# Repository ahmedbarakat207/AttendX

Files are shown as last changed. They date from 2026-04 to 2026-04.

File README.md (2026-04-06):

<div align="center">

# AttendX

**RFID-based Attendance Management System**

*ESP32 · MFRC522 · SSD1306 OLED · DS1302 RTC · Built-in Web Dashboard*





</div>

---

# Gallary

WhatsApp Image 2026-04-06 at 20 09 28

WhatsApp Image 2026-04-06 at 12 34 46

---

## What is AttendX?

AttendX is a self-contained, battery-powered attendance system. Students tap an RFID card — the device logs the scan with a timestamp and makes the record instantly available on a built-in web dashboard accessible from any phone or laptop. No internet connection, no external server, no apps to install.

The ESP32 acts as its own Wi-Fi access point. Everything runs on the device.

---

## Features

- **RFID scanning** — ISO 14443-A cards via MFRC522
- **OLED display** — 9 display modes, yellow/blue SSD1306
- **Built-in web dashboard** — admin panel served directly from ESP32
- **Battery powered** — 3.7 V Li-ion + TP4056 USB-C charger
- **DS1302 RTC** — keeps time through power cuts (CR2032 backup)
- **Dual Wi-Fi** — standalone AP mode or connect to existing network
- **SPIFFS storage** — student roster and attendance records survive reboots
- **CSV export** — download attendance sheet from the dashboard
- **Real-time updates** — SSE push to admin panel on every scan
- **One-button navigation** — cycle OLED modes without touching a phone

---

## Hardware

### Bill of Materials

| Component | Qty | Notes |
|---|-----|---|
| ESP32 Dev Board | 1 | Dual-core 240 MHz, 4 MB flash |
| MFRC522 RFID Module | 1 | 13.56 MHz, ISO 14443-A |
| SSD1306 OLED 0.96" | 1 | 128×64 px, I2C |
| DS1302 RTC Module | 1 | With CR2032 coin cell |
| CR2032 Coin Cell | 1 | RTC backup battery |
| TP4056 Charger Board | 1 | USB Type-C |
| Li-ion Battery 3.7 V | 1 | 18650 or flat LiPo |
| Tactile Button | 1 | OLED mode cycling |
| Power Switch | 1 | SPDT |
| 3D Printed Housing | 1 | 120 × 90 × 35 mm, 1.2 mm walls |

### Wiring

#### MFRC522 RFID → ESP32

| RFID Pin | ESP32 Pin |
|---|---|
| 3.3 V | 3.3 V rail |
| GND | GND |
| RST | GPIO 4 |
| SDA (SS) | GPIO 5 |
| MOSI | GPIO 23 |
| MISO | GPIO 19 |
| SCK | GPIO 18 |
| IRQ | — (not connected) |

#### SSD1306 OLED → ESP32

| OLED Pin | ESP32 Pin |
|---|---|
| VCC | 3.3 V rail |
| GND | GND |
| SCL | GPIO 22 |
| SDA | GPIO 21 |

#### DS1302 RTC → ESP32

| RTC Pin | ESP32 Pin | Notes |
|---|---|---|
| VCC | 3.3 V rail | |
| GND | GND | |
| CLK | GPIO 17 (TX2) | Repurposed UART2 TX |
| DAT | GPIO 16 (RX2) | Repurposed UART2 RX |
| RST | GPIO 1 (TX0) | Repurposed UART0 TX — USB Serial disabled |

#### Other

| Signal | ESP32 Pin |
|---|---|
| Button | GPIO 15 (INPUT_PULLUP) |
| Speaker | GPIO 2 |

> ⚠️ **All peripherals run on the 3.3 V rail. Do not connect anything to VIN/5 V.**  
> ⚠️ USB Serial (`Serial.print`) is **disabled** — GPIO1 (TX0) is used by the DS1302 RST line.

---

## Software

### Required Libraries

Install all of these from the Arduino Library Manager:

| Library | Purpose |
|---|---|
| `Adafruit GFX` | Graphics primitives |
| `Adafruit SSD1306` | OLED driver |
| `ArduinoJson` (v6) | JSON parsing / serialization |
| `ESPAsyncWebServer` | Async HTTP server |
| `AsyncTCP` | Dependency for ESPAsyncWebServer |
| `MFRC522` | RFID reader driver |
| `Rtc by Makuna` | DS1302 RTC driver (includes ThreeWire) |

### Arduino IDE Settings

| Setting | Value |
|---|---|
| Board | ESP32 Dev Module |
| Partition Scheme | **Default 4MB with spiffs** |
| Upload Speed | 921600 |

---

## Configuration

Edit these constants at the top of `main.ino` before flashing:

```cpp
const char *AP_SSID    = "AttendX";   // Wi-Fi hotspot name (open — no password)
const char *ADMIN_PASS = "1202";      // Web admin panel password
const long  GMT_OFFSET = 7200;        // UTC offset in seconds (UTC+2 = 7200)
const int   DST_OFFSET = 0;           // Daylight saving offset
const char *NTP_SERVER = "pool.ntp.org";
```

---

## Getting Started

### 1. Flash the firmware

1. Open `main.ino` in Arduino IDE
2. Select **ESP32 Dev Module** and set partition scheme to **Default 4MB with spiffs**
3. Set your `GMT_OFFSET` and `ADMIN_PASS`
4. Upload the sketch

### 2. Connect to AttendX

1. Power on the device — the OLED shows the ready screen after ~3 seconds
2. On your phone or laptop, connect to Wi-Fi: **`AttendX`** *(open network, no password)*
3. Open a browser and go to **`http://192.168.4.1`**
4. Log in with your admin password

### 3. Enroll students

1. Click **+ Add Student** in the dashboard
2. Enter name, student ID, and subject
3. Click **Next → Scan Card**
4. The student taps their RFID card to the reader
5. Done — student appears in the table

### 4. Take attendance

Students tap their card → OLED shows ✓ ACCESS GRANTED → dashboard updates live.

---

## Time Management

AttendX uses a **3-level time priority system**:

```
1. NTP sync (automatic, when connected to internet via STA mode)
        ↓ writes result to DS1302
2. DS1302 restore (automatic at boot, keeps time through power cuts)
        ↓ fallback if RTC battery is dead
3. Manual set (via web dashboard "Set Time" button or button menu)
        ↓ also writes to DS1302
```

In **AP-only mode** (no internet), the DS1302 maintains the clock as long as the CR2032 coin cell is alive. Set the time once from the admin dashboard and it persists indefinitely.

---

## OLED Display Modes

The physical button cycles through modes. Long-press (≥1 s) enters settings.

| Mode | Description | Trigger |
|---|---|---|
| `MODE_READY` | Clock, date, scan prompt | Default / idle |
| `MODE_SCAN_RESULT` | ✓ / ✗ with student name | After card tap (auto-returns in 4 s) |
| `MODE_ENROLL` | "SCAN CARD — For: \<name\>" | Web admin → Add Student |
| `MODE_ATTENDED` | Count of present students | Button press |
| `MODE_ABSENT` | Count of absent students | Button press |
| `MODE_WEBLINK` | IP address for admin panel | Button press |
| `MODE_SETTINGS` | AP Only / AP+WiFi / Set Time | Long press |
| `MODE_SET_TIME` | Field-by-field time entry | From Settings |
| `MODE_RESTART` | "Settings saved, please restart" | After saving Wi-Fi |

---

## Web Dashboard

| Page | URL | Auth |
|---|-----|---|
| Admin Login | `/` | — |
| Admin Dashboard | `/admin` | ✅  Token |
| WiFi Setup | `/wifi-setup` | ✅ Token |
| Student Page | `/student` | — |

### API Endpoints

All `/api/` endpoints except `/api/login` require header `X-Token: <token>`.

| Method | Endpoint | Description |
|---|---|---|
| `POST` | `/api/login` | Login, returns session token |
| `GET` | `/api/students/today` | Students + today's attendance |
| `POST` | `/api/enroll/start` | Begin card enrollment |
| `POST` | `/api/enroll/cancel` | Cancel enrollment |
| `DELETE` | `/api/students/:uid` | Remove student |
| `POST` | `/api/students/attend` | Mark student present |
| `POST` | `/api/students/unattend` | Mark student absent |
| `POST` | `/api/students/attend-all` | Mark all present |
| `POST` | `/api/students/absent-all` | Mark all absent |
| `POST` | `/api/settime` | Set device RTC from epoch timestamp |
| `GET` | `/api/wifi/scan` | Scan nearby Wi-Fi networks |
| `POST` | `/api/wifi` | Save Wi-Fi credentials |
| `POST` | `/api/reset` | Wipe all data |
| `GET` | `/events` | SSE stream for real-time scan events |

---

## Data Storage (SPIFFS)

| File | Content |
|---|---|
| `/students.json` | Student roster (uid, name, studentId, subject) |
| `/attendance.json` | Scan log (uid, date, timestamp) |
| `/config.json` | Wi-Fi credentials and mode |

Only the **first scan per student per day** is recorded. Subsequent taps show "Already Scanned".

---

## Troubleshooting

| Problem | Fix |
|---|-----|
| OLED blank | Check I2C address (0x3C or 0x3D). Verify SDA=21, SCL=22 |
| RFID not reading | Check SPI wiring. Confirm 3.3 V power only |
| Can't connect to AttendX | Network is open — no password needed. Try forgetting/re-joining |
| Wrong time after boot | DS1302 coin cell may be dead. Set time from admin dashboard to reprogram RTC |
| Time resets to 1970 | Replace CR2032 cell, then set time again |
| Students lost after restart | Partition scheme must be "Default 4MB with spiffs" |
| SSE not updating | Use Chrome or Firefox. Check browser console for EventSource errors |

---

## Project Team

| Name | Role |
|---|---|
| **Ahmed Barakat** | Team Leader / Embedded Developer |
| **Abdulrahman Yossef** | 3D Model / Housing Designer |
| **Menna Khattab** | Web Developer |
| **Hana Nasef** | Hardware Engineer |
| **Hana Elbirmawy** | Hardware Engineer |

---

<div align="center">

**AttendX** — RFID Attendance System &nbsp;·&nbsp; Version 1.0 &nbsp;·&nbsp; March 2026

</div>

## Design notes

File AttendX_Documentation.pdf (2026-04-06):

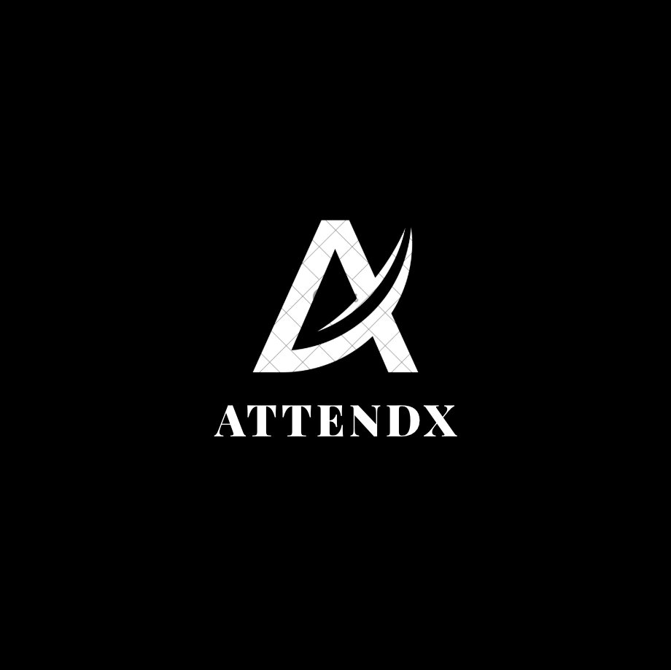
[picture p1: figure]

# RFID Attendance System

## Full Technical Documentation

ESP32 · MFRC522 RFID · SSD1306 OLED · Web Dashboard

Version 1.0 — March 2026

AttendX — Technical Documentation | Page 2
AttendX RFID Attendance System | ESP32 + MFRC522 + SSD1306

## 1. Project Overview

AttendX is a self-contained, battery-powered RFID attendance management system built around an ESP32 microcontroller. Students tap an RFID card to the reader; the device logs the scan with a timestamp and makes the record available on a built-in web dashboard that teachers or administrators access from any phone or laptop on the same network. No internet connection is required — the ESP32 acts as its own Wi-Fi access point.

### Key Features

- RFID Card Scanning — Instant student identification via ISO 14443-A RFID cards (MFRC522 reader).
- OLED Status Display — 128×64 SSD1306 OLED shows real-time clock, scan results, and attendance summaries.
- Built-in Web Server — Full-featured admin dashboard served directly from the ESP32 over Wi-Fi.
- SPIFFS Storage — Student roster and attendance records persisted in flash — survives restarts.
- Dual Wi-Fi Mode — Works as a standalone Access Point (AP) or connects to an existing network (STA+AP).
- Battery Powered — 3.7 V Li-ion cell charged via TP4056 board (USB Type-C).
- One-Button Navigation — Physical button cycles through OLED display modes without needing the web UI.
- CSV Export — Attendance data downloadable as a CSV spreadsheet from the admin panel.
- NTP Time Sync — Automatic time sync when internet is available; manual fallback via web UI.

AttendX — Technical Documentation | Page 3

## 2. Hardware

### 2.1 Bill of Materials

Component | Qty | Notes
MFRC522 RFID Module | 1 | SPI interface, 13.56 MHz, ISO 14443-A
ESP32 Dev Board | 1 | Dual-core 240 MHz, 4 MB flash, Wi-Fi + BT
0.96" SSD1306 OLED | 1 | 128×64 px, I2C address 0x3C
TP4056 Charger Board | 1 | USB Type-C, 1 A charge current
Li-ion Battery 3.7 V | 1 | Suitable capacity (e.g. 18650 or flat LiPo)
DS1302 RTC Module | 1 | Hardware real-time clock with coin-cell backup (CR2032)
CR2032 Coin Cell | 1 | Backup battery for DS1302 — keeps time when main power is off
Breadboard | 1 | For prototyping
Power Switch | 1 | SPDT slide or toggle
Tactile Button | 1 | OLED display-mode cycling
Type-C Cable | 1 | Charging

### 2.2 Pin Connections

MFRC522 RFID Reader → ESP32

Signal | ESP32 Pin | Notes
3.3 V | 3.3 V rail | Do NOT connect to 5 V — max 3.6 V
RST | GPIO 4 | Software reset line
GND | GND | Common ground
IRQ | — | Not connected
MISO | GPIO 19 | SPI Master-In-Slave-Out
MOSI | GPIO 23 | SPI Master-Out-Slave-In
SCK | GPIO 18 | SPI clock
SDA (SS/CS) | GPIO 5 | SPI chip-select

SSD1306 OLED Display → ESP32

Signal | ESP32 Pin | Notes
VCC | 3.3 V rail | Use 3.3 V — do not use VIN/5 V for OLED or RFID
GND | GND | Common ground

AttendX — Technical Documentation | Page 4
SCL | GPIO 22 | I2C clock
SDA | GPIO 21 | I2C data

DS1302 RTC Module → ESP32

Signal | ESP32 Pin | Notes
VCC | 3.3 V rail | Connect to 3.3 V only — do NOT use 5 V or VIN
GND | GND | Common ground
CLK | GPIO 17 (TX2) | Serial clock — TX2 repurposed as DS1302 CLK
DAT | GPIO 16 (RX2) | Bidirectional data — RX2 repurposed as DS1302 DAT
RST | GPIO 1 (TX0) | Chip-enable — TX0 repurposed; all 4 UART pins used by DS1302

All four ESP32 UART pins (GPIO16/RX2, GPIO17/TX2, GPIO1/TX0, GPIO3/RX0) are now fully committed to other functions — GPIO16/17 to the DS1302 and the remaining two to future expansion or left unconnected. Because TX0 (GPIO1) is used as DS1302 RST, USB Serial debugging is disabled in firmware (Serial.begin is commented out). This is intentional for the final production build.

Other Connections

Signal | ESP32 Pin | Notes
Button | GPIO 15 | Pull-up; active LOW
Speaker / Buzzer | GPIO 2 | Optional audio feedback
Battery + | 3.3 V rail (via TP4056 + regulator) | TP4056 output → 3.3 V LDO → 3.3 V rail

### 2.3 Housing

The enclosure is a 3-D printed box (120 mm × 90 mm × 35 mm) with 1.2 mm thick walls. Cut-outs are provided for: the USB Type-C charging port, the power switch, the OLED display window, the RFID scanning area (wall must be ≤1.2 mm plastic over the antenna), and the tactile button. The RFID antenna should face outward through the thinnest possible plastic to maximise read range.

AttendX — Technical Documentation | Page 5

## 3. Software Architecture

The firmware is a single Arduino sketch (main.ino) compiled for the ESP32 Arduino core. All logic runs in a cooperative loop — there are no RTOS tasks. The major subsystems are:

- Wi-Fi / Web Server — ESPAsyncWebServer serves HTML pages and a REST API on port 80. An AsyncEventSource endpoint (/events) streams real-time scan events to the admin page via SSE.
- RFID Polling — The main loop calls rfid.PICC_IsNewCardPresent() every iteration. On card detect, the UID is looked up in the student roster and a record written to SPIFFS.
- OLED Display — A DisplayMode enum (9 modes) controls what is shown. Mode transitions happen on button press, after scan events, or on API commands.
- SPIFFS Persistence — Two JSON files store data: /students.json (roster) and /attendance.json (scan log). Both are loaded into DynamicJsonDocument objects; writes happen synchronously.
- Time Management — NTP sync via pool.ntp.org when STA mode is active. Manual time can be set from the web UI (POST /api/settime) or with the physical button in MODE_SET_TIME.
- Session Auth — Admin login issues a random 16-character hex token stored in a global variable. All protected API endpoints check the token header.
- DS1302 RTC — A hardware real-time clock (DS1302) is connected via a 3-wire serial interface. On boot the ESP32 restores the current time from the RTC. After any NTP sync or manual time-set the new time is written back to the RTC so it survives power cuts.

### 3.1 Configuration Constants

Edit these at the top of main.ino before flashing:

Constant | Default | Description
AP_SSID | AttendX | Name of the ESP32 Wi-Fi access point (open — no password)
ADMIN_PASS | 1202 | Admin web-panel password
GMT_OFFSET | 7200 | Seconds east of UTC (e.g. UTC+2 = 7200)
DST_OFFSET | 0 | Daylight-saving offset in seconds
NTP_SERVER | pool.ntp.org | NTP server hostname

### 3.2 REST API Reference

All endpoints under /api/ except /api/login require header: X-Token:

Method | Endpoint | Auth | Description
POST | /api/login | No | Login — body: {"password":"..."} — returns token
GET | /api/students | Yes | Return full student roster as JSON array
POST | /api/students | Yes | Add student — body: {name, studentId, subject, uid}
DELETE | /api/students/ | Yes | Remove student by UID
GET | /api/attendance | Yes | Return today's attendance records

AttendX — Technical Documentation | Page 6
POST | /api/attendance/mark | Yes | Manually mark student present or absent
POST | /api/attendance/attend-all | Yes | Mark all students present
POST | /api/attendance/absent-all | Yes | Mark all students absent
POST | /api/clearall | Yes | Wipe all students and attendance data
GET | /api/attendance/csv | Yes | Download attendance as CSV file
POST | /api/setenroll | Yes | Put device into card-enroll mode for a student
POST | /api/settime | Yes | Set device RTC — body: {"epoch": unix_timestamp}
GET | /api/scanwifi | Yes | Trigger Wi-Fi scan, returns list of SSIDs
POST | /api/setwifi | Yes | Save Wi-Fi credentials — body: {ssid, password}
POST | /api/restart | Yes | Software-restart the ESP32
GET | /events | Yes | SSE stream — scan events pushed in real time

AttendX — Technical Documentation | Page 7

## 4. OLED Display Modes

The SSD1306 128×64 OLED cycles through nine distinct modes controlled by the DisplayMode enum. The top 14 pixels always show an inverted (black-on-white) header bar. A horizontal separator line divides the content area from the status bar at the bottom.

Mode 1 / 9 | Ready / Idle
Constant | MODE_READY
Display | Default state. Header: 'AttendX'. Centre: current time in large font. Below: current date. Bottom: 'Scan your card...' Transitions to MODE_SCAN_RESULT on any card tap.
Trigger | Shown whenever the device is idle and waiting for a card.
Mode 2 / 9 | Scan Result
Constant | MODE_SCAN_RESULT
Display | Header changes to 'ACCESS GRANTED', 'ALREADY SCANNED', or 'ACCESS DENIED'. Left side shows a large tick (✓) on success or a cross (✗) on failure. Right side shows student name and status message. Bottom bar shows current time. Displayed for ~3 seconds.
Trigger | Automatically returns to MODE_READY after 3 seconds.
Mode 3 / 9 | Card Enroll
Constant | MODE_ENROLL
Display | Header: 'ENROLL STUDENT'. Centre: large 'SCAN CARD'. Bottom: 'For: ' (truncated to 17 characters). Active while the device waits for a new card.
Trigger | Entered via web admin Add Student → Next → Scan Card. Exits when card is read or cancelled.
Mode 4 / 9 | Attended Count
Constant | MODE_ATTENDED
Display | Header: 'ATTENDED TODAY'. Left: tick icon. Right: large 3× font count of students present today. Bottom: '[BTN] Next'.
Trigger | Reached by pressing the physical button from the Ready screen.
Mode 5 / 9 | Absent Count
Constant | MODE_ABSENT
Display | Header: 'ABSENT TODAY'. Left: cross icon. Right: large count of absent students (total enrolled minus present). Bottom: '[BTN] Next'.
Trigger | Reached by pressing the button from MODE_ATTENDED.

AttendX — Technical Documentation | Page 8
Mode 6 / 9 | Web Link
Constant | MODE_WEBLINK
Display | Header: 'ADMIN PANEL'. Shows 'Open browser:' then 'http://' and the AP IP address (default 192.168.4.1). If STA mode is active, the STA IP is also shown at the bottom.
Trigger | Reached by pressing the button from MODE_ABSENT.
Mode 7 / 9 | Settings Menu
Constant | MODE_SETTINGS
Display | Header: 'SETTINGS'. Three options: '[ ] AP Only', '[x] AP+WiFi', 'Set Time'. Current selection highlighted with '>'. Short-press navigates; long-press confirms.
Trigger | Reached by pressing the button from MODE_WEBLINK.
Mode 8 / 9 | Manual Time Set
Constant | MODE_SET_TIME
Display | Header: 'SET TIME'. Five editable fields: Hour, Minute, Day, Month, Year. Current field is underlined. Short press increments value; long press advances to next field. After Year field, long-press saves and applies the time.
Trigger | Entered from MODE_SETTINGS when 'Set Time' is selected. Used when no internet for NTP.
Mode 9 / 9 | Restart Notice
Constant | MODE_RESTART
Display | Header: 'WIFI SAVED'. Centre: 'Settings saved! / Please restart / the device.'
Trigger | Triggered by POST /api/setwifi. Cleared on next device boot.

AttendX — Technical Documentation | Page 9

## 5. Web Dashboard

The admin dashboard is served directly from the ESP32 as inline PROGMEM HTML+JS. No external server or internet connection is needed. Open a browser and navigate to http://192.168.4.1 (AP mode) or the STA IP shown on the OLED.

Login Page (/)
Password-protected entry. Default password: 1202 (change ADMIN_PASS in firmware). On success a session token is stored in sessionStorage and the browser redirects to /admin. A 'Submit Attendance' link is also available for the student-facing page.

Admin Dashboard (/admin)
Main control panel. Shows three stat counters (total students, present, absent). Three tab filters: All Students / Present / Absent. Table lists every student with name, ID/UID, subject, status badge, scan time, and action buttons. Top-right toolbar: Set Time, WiFi Setup, Clear All Data, Logout.

Add Student Modal
Opened by '+ Add Student'. Fields: Full Name, Student ID (optional), Subject. Clicking 'Next → Scan Card' sends data to /api/setenroll, putting the device into card-enroll mode. The OLED shows MODE_ENROLL and waits for a card tap.

WiFi Setup Page (/wifi)
Scans nearby networks via /api/scanwifi. Click a network to pre-fill SSID; enter password and save. Credentials stored in SPIFFS /config.json. Device must be restarted to apply.

Set Time Modal
Sends the browser's current epoch timestamp to /api/settime so the device RTC is synchronised with the admin's device. Useful in AP-only mode where NTP is unavailable.

Student Page (/student)
Minimal page for students to verify their own attendance status using their UID. Not password protected.

Real-Time SSE Alerts
The admin dashboard subscribes to /events. Every card scan pushes a JSON event; a toast notification pops up with the student name and result without needing a page refresh.

AttendX — Technical Documentation | Page 10

## 6. How to Use

### 6.1 First-Time Setup

- Step 1: Flash the firmware using Arduino IDE with ESP32 board support installed.
- Step 2: Install required libraries: Adafruit GFX, Adafruit SSD1306, ArduinoJson (v6), ESPAsyncWebServer, AsyncTCP, MFRC522, and "Rtc by Makuna" (includes ThreeWire + RtcDS1302).
- Step 3: In Tools → Board select 'ESP32 Dev Module'. Set Partition Scheme to 'Default 4MB with spiffs'.
- Step 4: Set ADMIN_PASS and GMT_OFFSET constants to your values, then upload.
- Step 5: Power on the device. The OLED shows MODE_READY after ~3 seconds.
- Step 6: On your phone or laptop, connect to Wi-Fi network 'AttendX' (password: 12345678).
- Step 7: Open a browser and go to http://192.168.4.1
- Step 8: Log in with your admin password.

### 6.2 Enrolling Students

- In the admin dashboard click '+ Add Student'.
- Enter the student's Full Name, an optional Student ID, and their Subject.
- Click 'Next → Scan Card'. The OLED switches to MODE_ENROLL.
- The student taps their RFID card to the reader. The UID is captured and saved.
- The modal closes and the student appears in the table with Absent status.

### 6.3 Taking Attendance (Daily Use)

- Power on the device at the start of class.
- The OLED displays the current time and 'Scan your card...'
- Each student taps their registered card. The OLED confirms 'ACCESS GRANTED' with a tick and the student's name.
- If a card is already scanned today, it shows 'ALREADY SCANNED'.
- An unknown card shows 'ACCESS DENIED'.
- The admin dashboard updates in real time via SSE — no refresh needed.
- After class, download the CSV from the admin panel for your records.

### 6.4 Button Navigation

The physical button on GPIO 15 navigates OLED display modes:

Action | Result
Short press (< 2 s) | Advance to next display mode in the cycle
Long press (≥ 2 s) | Confirm selection in Settings / Set Time modes

Button cycle order: Ready → Attended → Absent → Web Link → Settings → Ready

### 6.5 Connecting to School Wi-Fi (Optional)

AttendX — Technical Documentation | Page 11
- In the admin dashboard click 'WiFi Setup'.
- Click 'Scan For Networks' — nearby SSIDs appear with signal strength.
- Click your network name, enter the password, and save.
- The OLED shows MODE_RESTART. Power-cycle the device.
- On boot the ESP32 connects to your network AND keeps its own AP running. NTP sync runs automatically and the result is saved to the DS1302 RTC.
- The OLED Web Link screen now shows both the AP IP and the STA (school network) IP.

### 6.6 Setting the Time Manually (No Internet)

- Press the button from the Web Link screen to reach Settings.
- Short-press to highlight 'Set Time', then long-press to enter MODE_SET_TIME.
- Short-press increments the currently underlined field (Hour → Min → Day → Month → Year).
- Long-press advances to the next field. After Year, the time is applied.
- Alternatively, use the 'Set Time' button in the admin dashboard to sync from your browser.

AttendX — Technical Documentation | Page 12

## 7. Data Storage

All persistent data is stored in the ESP32 SPIFFS (SPI Flash File System). The partition must be at least 1 MB; the default 4 MB partition scheme leaves ~1.5 MB for SPIFFS.

### 7.1 /students.json — Student Roster

[
{
"uid": | "A1:B2:C3:D4", | // RFID card UID (hex, colon-separated)
"name": | "Ahmed Hassan",
"studentId": "S001", | // Optional
"subject": | "IT"
}
]

### 7.2 /attendance.json — Attendance Log

[
{
"uid": | "A1:B2:C3:D4",
"timestamp": "2026-03-28T07:22:00", // ISO-8601 local time
"date": | "2026-03-28",
"time": | "07:22"
}
]
Only the first scan of the day per student is recorded. Subsequent taps show 'ALREADY SCANNED' but do not add a duplicate record.

### 7.3 /config.json — Wi-Fi Config

{
"useSta": true,
"ssid": "SchoolNetwork",
"password":"secret123"
}
Written by POST /api/setwifi. Read at boot by loadConfig(). If the file is missing or malformed, the device falls back to AP-only mode.

AttendX — Technical Documentation | Page 13

## 8. Troubleshooting

■ OLED shows nothing
Check I2C address. Most SSD1306 modules use 0x3C (OLED_ADDR in code). Some use 0x3D — change OLED_ADDR accordingly. Verify SDA=21, SCL=22.

■ RFID card not detected
Ensure 3.3 V power only. Check SPI wiring: MISO=19, MOSI=23, SCK=18, SS=5, RST=4. Try reducing the distance — max reliable read range is ~3 cm.

■ Cannot connect to AttendX AP
Confirm Wi-Fi is not disabled on your device. The AP password is 12345678. Try forgetting and re-joining the network.

■ Admin panel shows wrong time
If no internet, use the 'Set Time' button in the dashboard or navigate to MODE_SET_TIME with the button. Verify GMT_OFFSET is correct for your timezone.

■ Students not saving after restart
Make sure the partition scheme is set to 'Default 4MB with spiffs' in Arduino IDE. Upload the sketch once with Tools → ESP32 Sketch Data Upload to format SPIFFS.

■ 'Already Scanned' appears immediately
The attendance.json from a previous day may still have records. Use 'Clear All Data' in the dashboard, or implement a daily auto-reset in the firmware.

■ SSE events not appearing in dashboard
Some browsers block SSE on http:// pages. Use Chrome or Firefox. Check the browser console for EventSource errors.

■ Time resets to 1970 after power-off
The DS1302 coin cell (CR2032) may be dead or missing. Replace the coin cell and re-set the time from the admin dashboard or button menu. Also check that CLK=GPIO17, DAT=GPIO16, RST=GPIO1 wiring is correct and VCC is on the 3.3 V rail.

■ DS1302 shows wrong time after power-on
The RTC was never written. Ensure you set the time via the admin panel (Set Time button) or via the button menu (Settings > Set Time) at least once so the DS1302 gets programmed. In STA mode this happens automatically after NTP sync.

■ Wi-Fi STA not connecting after restart
Verify the saved SSID/password in /config.json. Use WiFi Setup again if needed. The ESP32 tries STA for ~10 seconds; if it fails it continues in AP-only mode.

AttendX — Technical Documentation | Page 14

## 9. Specifications Summary

Parameter | Value
Microcontroller | ESP32 (Xtensa LX6, dual-core 240 MHz)
Flash Memory | 4 MB (1.5 MB SPIFFS for data)
Wi-Fi | 802.11 b/g/n 2.4 GHz — AP + STA dual mode
RFID Standard | ISO 14443-A, 13.56 MHz
RFID Module | MFRC522 (SPI interface)
Display | SSD1306 128×64 OLED (I2C, 0x3C)
Battery | 3.7 V Li-ion, charged via TP4056 USB-C
Operating Voltage | 3.3 V (ESP32 + RFID + OLED)
Housing | 3-D printed, 120×90×35 mm, 1.2 mm walls
Web Server | ESPAsyncWebServer on port 80
Data Format | JSON (ArduinoJson v6)
Time Sync | NTP (pool.ntp.org) or manual (web UI / button)
RTC Module | DS1302 (3-wire serial, CR2032 backup battery)
RTC Pins | CLK=GPIO17 (TX2), DAT=GPIO16 (RX2), RST=GPIO1 (TX0), VCC=3.3 V rail
Time Priority | 1) NTP (STA mode) 2) DS1302 restore 3) Manual
Estimated Cost | ~750 EGP
AttendX RFID Attendance System | Technical Documentation v1.0 | March 2026

AttendX — Technical Documentation | Page 15

## 10. OLED Display — Visual Reference

The SSD1306 OLED uses a yellow zone for the top 16 pixels (header bar) and a blue zone for the remaining 48 pixels. Below are rendered illustrations of all nine display modes as they appear on the physical device.

MODE_READY — Idle screen showing time, date, and scan prompt.

MODE_SCAN_RESULT — Access granted: tick icon, student name, timestamp.

MODE_SCAN_RESULT — Access denied: cross icon for unknown card.

MODE_ENROLL — Waiting for a new card tap to register a student.

MODE_ATTENDED — Large count of students present today.

MODE_ABSENT — Large count of absent students today.

MODE_WEBLINK — Admin panel IP addresses for browser access.

MODE_SETTINGS — Wi-Fi mode selection menu.

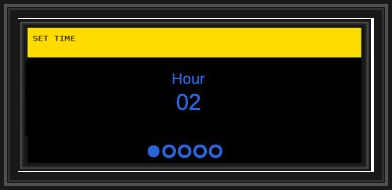
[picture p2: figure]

MODE_SET_TIME — Manual time/date entry using the button.

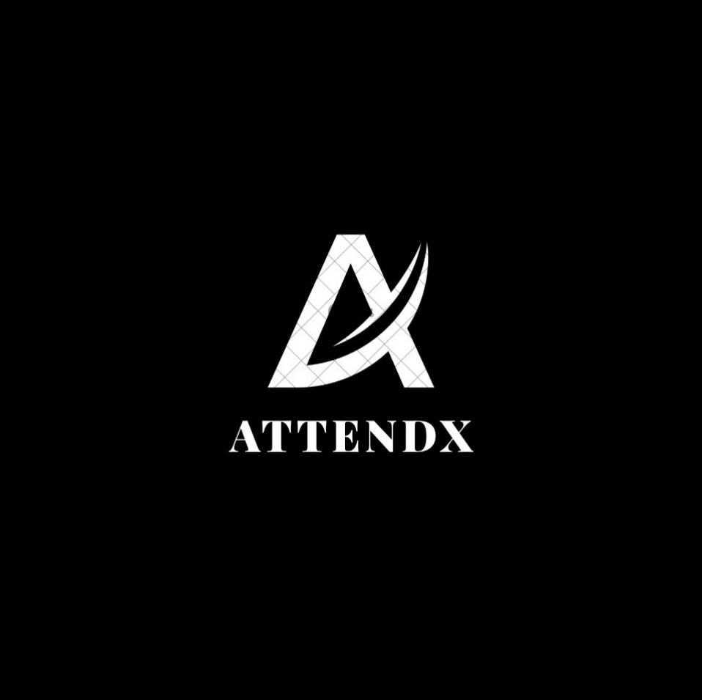
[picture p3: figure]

# Project Team

Ahmed Barakat | Team Leader / Embedded Developer
Abdulrahman Yossef | 3D Model / Housing Designer
Menna Khattab | Web Developer
Hana Nasef | Hardware Engineer
Hana Elbirmawy | Hardware Engineer
AttendX - RFID Attendance System | Version 1.0 | March 2026

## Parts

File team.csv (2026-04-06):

ID | Name | Role | Contribution
20250094 | احمد محمد عامر ابراهيم بركات | Team Leader / Embedded / Backend Developer | Wrote the main.ino file with all the Backend Functions
20250439 | عبدالرحمن يوسف ابراهيم يوسف علي | 3D Model Designer | Designed the 3D Housing
20250853 | منه الله فتح محمد خطاب | Front-End Website Developer | Designed the Admin Dashboard
20250908 | هنا محمود السيد ابواليزيد البرماوي | Hardware Engineer | Choosing all the parts and Connecting them all together
20250909 | هنا ناصف عبدالله عبدالقادر القط | Hardware Engineer | Choosing all the parts and Connecting them all together

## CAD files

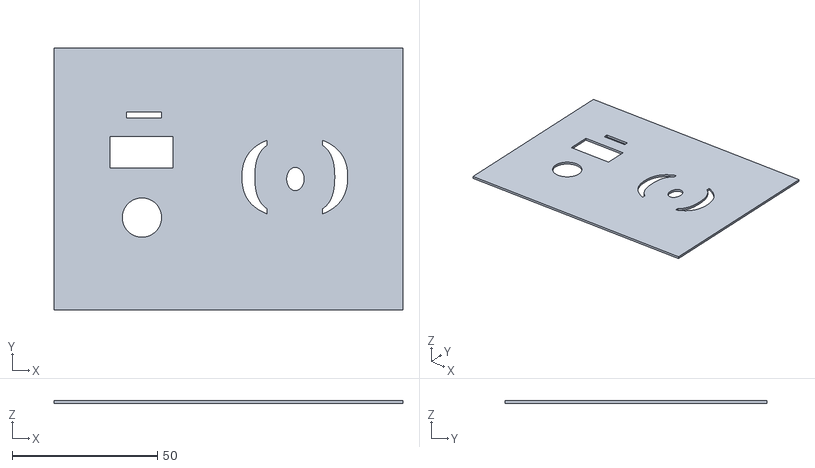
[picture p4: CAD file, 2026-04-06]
top.stl
120.0 x 90.0 x 1.00

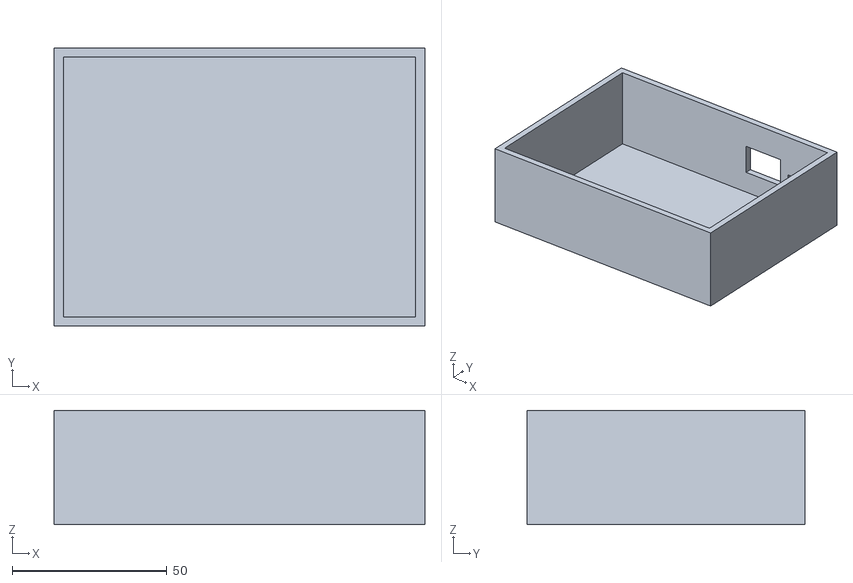
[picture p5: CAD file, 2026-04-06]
bottom.stl
120.0 x 90.0 x 37.0

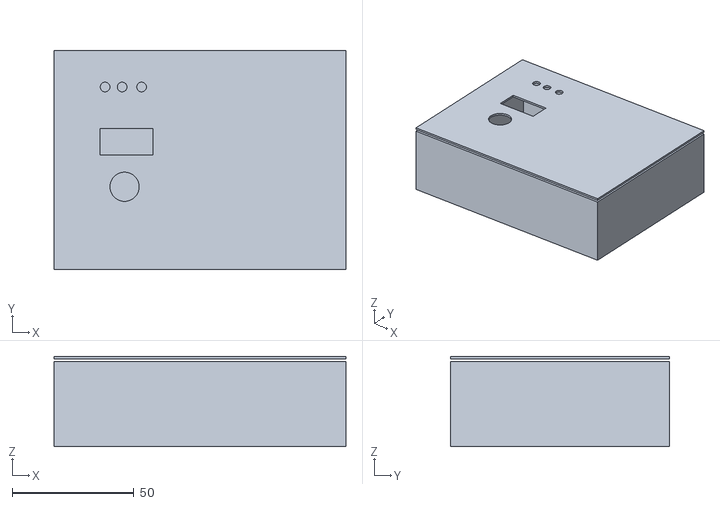
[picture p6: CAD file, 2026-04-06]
project.stl
120.0 x 90.0 x 37.0

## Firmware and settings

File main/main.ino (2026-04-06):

/*
  ==============================
  AttendX RFID Attendance System
  ==============================

  a Project for FCI, Tanta University Provided to Dr. Aida Naser

  Parts:
    ESP32
    RFID Scanner
    DS1302 RTC
    0.96 I2C OLED Display at Address 0x3C
    a Small Phone's Speaker
    12mm*12mm Push Button
    400mah Li-ion Battery (good for about 3 Hours of contiuous Use)
    TP4056 Micro USB BMS Board
    400 Points Breadboard
    Custom 3D-Printed Shell

  Contributers:
    Ahmed Barakat - Team Leader / Backend Embedded Developer (Responsible for the Arduino / Website's Backend Code)
    Abdulrahman Yousef - Shell Designer (Responsible for the 3D Printed Housing)
    Menna Khattab - Frontend Web Developer (Responsible for the Design of the Admin Dashboard and some elemnets of the Backend (JSON Database and Password Entry))
    Hana Nasef - Hardware Engineer (Responsible for Connecting all the Parts Together)
    Hana ElBirmawy - Hardware Engineer (Responsible for Connecting all the Parts Together)
*/

#include <Adafruit_GFX.h>
#include <Adafruit_SSD1306.h>
#include <ArduinoJson.h>
#include <ESPAsyncWebServer.h>
#include <MFRC522.h>
#include <SPI.h>
#include <SPIFFS.h>
#include <WiFi.h>
#include <Wire.h>
#include <time.h>
#include <vector>
#include <ThreeWire.h>
#include <RtcDS1302.h>

const char *AP_SSID    = "AttendX";          
const char *ADMIN_PASS = "1202";             
const long  GMT_OFFSET = 7200;               
const int   DST_OFFSET = 0;
const char *NTP_SERVER = "pool.ntp.org";

#define RFID_RST_PIN  4
#define RFID_SS_PIN   5
#define BUTTON_PIN    15
#define OLED_SDA      21
#define OLED_SCL      22
#define SPEAKER_PIN   2
#define SCREEN_WIDTH  128
#define SCREEN_HEIGHT 64
#define OLED_RESET    -1
#define OLED_ADDR     0x3C
#define ATTEND_FILE   "/attendance.json"
#define STUDENTS_FILE "/students.json"
#define str String
#define DS1302_CLK_PIN  17   
#define DS1302_DAT_PIN  16   
#define DS1302_RST_PIN   1   


MFRC522            rfid(RFID_SS_PIN, RFID_RST_PIN);
Adafruit_SSD1306   display(SCREEN_WIDTH, SCREEN_HEIGHT, &Wire, OLED_RESET);
AsyncWebServer     server(80);
AsyncEventSource   sseSource("/events");
ThreeWire  rtcWire(DS1302_DAT_PIN, DS1302_CLK_PIN, DS1302_RST_PIN);
RtcDS1302<ThreeWire> rtc(rtcWire);

enum DisplayMode {
  MODE_READY,
  MODE_SCAN_RESULT,
  MODE_ENROLL,
  MODE_ATTENDED,
  MODE_ABSENT,
  MODE_WEBLINK,
  MODE_SETTINGS,
  MODE_RESTART,
  MODE_SET_TIME
};


bool useSta      = false;
String staSsid   = "";
String staPassword = "";
bool staConnected  = false;

unsigned long buttonPressStart = 0;
bool buttonHeld = false;
int settingsSelection = 0;


int tsField = 0;
int tsHour = 12, tsMin = 0, tsDay = 1, tsMonth = 1, tsYear = 2026;

DisplayMode   currentMode   = MODE_READY;
unsigned long lastScanTime  = 0;
unsigned long lastButtonPress = 0;
int           totalScansToday = 0;

str  enrollName    = "";
str  enrollSubject = "";
str  enrollStudId  = "";
bool enrollPending = false;
str  attendanceCache = "";
bool cacheDirty   = true;
str  activeToken  = "";
volatile bool pendingRestart = false;


void setupRoutes();
void drawCenteredText(const char *t, int y, bool large = false);
void showReady();
void showScanResult(bool ok, str name, str msg);
void showEnroll();
void showAttended();
void showAbsent();
void showWebLink();
void showRestart();
void showSettings();
void showSetTime();
void handleButton();
void connectWiFi();
void syncTime();
void writeRtcFromSystem();
void readRtcToSystem();
str  getCurrentTimestamp();
str  getCurrentDate();
str  getCurrentTimeDisplay();
str  getCurrentDateDisplay();
str  uidToString(byte *buf, byte len);
void loadConfig();
void saveConfig();
void applyManualTime();
bool processRFID(str uid, str &name, str &msg);



const char LOGIN_HTML[] PROGMEM = R"rawhtml(<!DOCTYPE html>
<html lang="en">
<head>
<meta charset="UTF-8">
<meta name="viewport" content="width=device-width,initial-scale=1">
<title>Admin Login</title>
<style>
body{background:linear-gradient(135deg,#00bcd4,#0288d1);font-family:'Segoe UI',sans-serif;display:flex;justify-content:center;align-items:center;height:100vh;margin:0}
.card{background:white;padding:40px 30px;border-radius:20px;box-shadow:0 15px 35px rgba(0,0,0,0.2);width:320px;text-align:center}
.title{color:#0288d1;margin-bottom:20px;font-size:26px;font-weight:bold}
.subtitle{color:#888;font-size:13px;margin-bottom:25px}
.rfid-icon{font-size:48px;margin-bottom:10px}
input{width:100%;padding:12px;margin:8px 0;border:1px solid #ddd;border-radius:10px;outline:none;transition:.3s;box-sizing:border-box;font-size:15px}
input:focus{border-color:#03a9f4;box-shadow:0 0 5px rgba(3,169,244,.5)}
button{background:linear-gradient(135deg,#03a9f4,#0288d1);color:white;border:none;padding:14px;border-radius:10px;cursor:pointer;font-weight:bold;width:100%;transition:.3s;font-size:15px;margin-top:8px}
button:hover{transform:scale(1.03);opacity:.9}
.err{color:#dc3545;font-size:13px;margin-top:10px;display:none}
.links{margin-top:20px;font-size:13px;color:#888}
.links a{color:#0288d1;text-decoration:none;font-weight:bold}
.links a:hover{text-decoration:underline}
</style>
</head>
<body>
<div class="card">
  <h2 class="title">AttendX</h2>
  <p class="subtitle">Admin Login</p>
  <input type="password" id="adminPass" placeholder="Enter Password" onkeydown="if(event.key==='Enter')login()">
  <button onclick="login()">Login</button>
  <div class="err" id="err">Incorrect Password!</div>
  <div class="links">
    Student? <a href="/student">Submit Attendance</a>
  </div>
</div>
<script>
async function login(){
  const pass=document.getElementById('adminPass').value;
  if(!pass){ document.getElementById('err').style.display='block'; document.getElementById('err').textContent='Enter password.'; return; }
  const r=await fetch('/api/login',{method:'POST',headers:{'Content-Type':'application/json'},body:JSON.stringify({password:pass})});
  if(r.ok){
    const d=await r.json();
    sessionStorage.setItem('token',d.token);
    window.location.href='/admin';
  } else {
    document.getElementById('err').style.display='block';
    document.getElementById('err').textContent='Incorrect password.';
    document.getElementById('adminPass').value='';
    document.getElementById('adminPass').focus();
  }
}
if(sessionStorage.getItem('token')) window.location.href='/admin';
</script>
</body>
</html>)rawhtml";
const char ADMIN_HTML[] PROGMEM = R"rawhtml(<!DOCTYPE html>
<html lang="en">
<head>
<meta charset="UTF-8">
<meta name="viewport" content="width=device-width,initial-scale=1">
<title>Admin Dashboard</title>
<style>
*{box-sizing:border-box;margin:0;padding:0}
body{background:#00bcd4;font-family:'Segoe UI',sans-serif;min-height:100vh;padding:20px 10px}
.page{max-width:800px;margin:0 auto;display:flex;flex-direction:column;gap:14px}
.card{background:#fff;border-radius:16px;box-shadow:0 6px 20px rgba(0,0,0,.12);padding:20px}
h2{color:#333;font-size:20px;margin-bottom:4px}
.sub{color:#888;font-size:12px;margin-bottom:14px}
.stats{display:grid;grid-template-columns:repeat(3,1fr);gap:10px;margin-bottom:6px}
.stat{background:#f8f9fa;border-radius:10px;padding:12px;text-align:center}
.stat-n{font-size:30px;font-weight:800;font-family:monospace}
.stat-n.green{color:#2ecc71}.stat-n.red{color:#e74c3c}.stat-n.blue{color:#3498db}
.stat-l{font-size:10px;text-transform:uppercase;letter-spacing:.06em;color:#888;margin-top:2px}
.tabs{display:flex;gap:6px;margin-bottom:14px}
.tab{flex:1;padding:9px;border:none;border-radius:8px;font-size:13px;font-weight:600;cursor:pointer;background:#f0f0f0;color:#666;transition:.2s}
.tab.active{background:#00bcd4;color:#fff}
.tbl-wrap{overflow-x:auto}
table{width:100%;border-collapse:collapse;font-size:13px}
th{padding:8px 10px;text-align:left;font-size:10px;text-transform:uppercase;letter-spacing:.08em;color:#888;border-bottom:2px solid #eee}
td{padding:10px 10px;border-bottom:1px solid #f0f0f0}
tr:last-child td{border-bottom:none}
tr:hover td{background:#f9fdff}
.badge{display:inline-flex;align-items:center;gap:4px;padding:3px 10px;border-radius:20px;font-size:11px;font-weight:700}
.badge.present{background:#d4edda;color:#155724}
.badge.absent{background:#f8d7da;color:#721c24}
.btn{padding:7px 14px;border-radius:8px;font-size:13px;font-weight:600;cursor:pointer;border:none;transition:.15s;font-family:inherit}
.btn:hover{filter:brightness(.93)}
.btn-teal{background:#00bcd4;color:#fff}
.btn-green{background:#2ecc71;color:#fff}
.btn-red{background:#e74c3c;color:#fff}
.btn-yellow{background:#f39c12;color:#fff}
.btn-gray{background:#ecf0f1;color:#555}
.btn-sm{padding:4px 10px;font-size:12px}
.action-bar{display:flex;gap:8px;flex-wrap:wrap;margin-bottom:12px;align-items:center}
.action-bar input{flex:1;min-width:140px;padding:8px 12px;border:1px solid #ddd;border-radius:8px;font-size:13px;outline:none}
.action-bar input:focus{border-color:#00bcd4}
.overlay{display:none;position:fixed;inset:0;background:rgba(0,0,0,.5);z-index:200;align-items:center;justify-content:center}
.overlay.open{display:flex}
.modal{background:#fff;padding:28px;border-radius:18px;width:360px;max-width:95vw;box-shadow:0 20px 50px rgba(0,0,0,.25)}
.modal h3{font-size:16px;margin-bottom:18px;color:#333}
.fg{margin-bottom:13px}
.fg label{display:block;font-size:11px;color:#888;text-transform:uppercase;letter-spacing:.07em;margin-bottom:5px;font-weight:600}
.fg input{width:100%;padding:10px 12px;border:1px solid #ddd;border-radius:8px;font-size:14px;outline:none;font-family:inherit}
.fg input:focus{border-color:#00bcd4}
.mfooter{display:flex;gap:8px;justify-content:flex-end;margin-top:18px}
.scan-wait{text-align:center;padding:20px}
.scan-icon{font-size:52px;margin-bottom:12px;animation:pulse 1.2s ease-in-out infinite}
@keyframes pulse{0%,100%{transform:scale(1)}50%{transform:scale(1.1)}}
.scan-name{font-size:18px;font-weight:700;color:#333;margin-bottom:6px}
.scan-hint{font-size:13px;color:#888}
#toast{position:fixed;bottom:20px;right:20px;background:#2ecc71;color:#fff;padding:12px 20px;border-radius:10px;font-weight:700;font-size:13px;z-index:999;transform:translateY(60px);opacity:0;transition:.3s;pointer-events:none}
#toast.show{transform:none;opacity:1}
#toast.err{background:#e74c3c}
#sse-alert{position:fixed;top:18px;right:18px;background:#fff;border-left:5px solid #2ecc71;border-radius:10px;padding:12px 16px;min-width:200px;box-shadow:0 6px 20px rgba(0,0,0,.15);z-index:999;transform:translateX(130%);transition:.3s;font-size:13px}
#sse-alert.show{transform:none}
#sse-alert.fail{border-left-color:#e74c3c}
.sa-name{font-weight:700;margin-bottom:2px}
.sa-msg{color:#888;font-size:12px}
.header-row{display:flex;align-items:flex-start;justify-content:space-between;gap:10px;flex-wrap:wrap}
.header-btns{display:flex;gap:8px;flex-shrink:0}
.btn-logout{background:#fff;color:#e74c3c;border:1px solid #e74c3c;padding:7px 16px;border-radius:8px;font-size:13px;font-weight:600;cursor:pointer;transition:.15s;font-family:inherit}
.btn-logout:hover{background:#fdf2f2}
.btn-settime{background:#fff;color:#f39c12;border:1px solid #f39c12;padding:7px 16px;border-radius:8px;font-size:13px;font-weight:600;cursor:pointer;transition:.15s;font-family:inherit}
.btn-settime:hover{background:#fffbf0}
.btn-clear{background:#fff;color:#888;border:1px solid #ccc;padding:7px 16px;border-radius:8px;font-size:13px;font-weight:600;cursor:pointer;transition:.15s;font-family:inherit}
.btn-clear:hover{background:#f8f8f8;border-color:#999}
.btn-wifi{background:#fff;color:#00838f;border:1px solid #00bcd4;padding:7px 16px;border-radius:8px;font-size:13px;font-weight:600;cursor:pointer;transition:.15s;font-family:inherit;text-decoration:none;display:inline-flex;align-items:center;gap:4px}
.btn-wifi:hover{background:#e0f7fa}
</style>
</head>
<body>
<div class="page">

  <div class="card">
    <div class="header-row">
      <div>
        <h2>AttendX</h2>
        <div class="sub" id="dateLabel"></div>
      </div>
      <div class="header-btns">
        <button class="btn-settime" onclick="openSetTime()">Set Time</button>
        <button class="btn-wifi" onclick="openWifiSetup()">WiFi Setup</button>
        <button class="btn-clear" onclick="clearAll()">Clear All Data</button>
        <button class="btn-logout" onclick="logout()">Logout</button>
      </div>
    </div>
    <div class="stats">
      <div class="stat"><div class="stat-n blue" id="stTotal">—</div><div class="stat-l">Students</div></div>
      <div class="stat"><div class="stat-n green" id="stPresent">—</div><div class="stat-l">Present</div></div>
      <div class="stat"><div class="stat-n red" id="stAbsent">—</div><div class="stat-l">Absent</div></div>
    </div>
  </div>

  <div class="card">
    <div class="tabs">
      <button class="tab active" onclick="switchTab('all')">All Students</button>
      <button class="tab" onclick="switchTab('present')">Present</button>
      <button class="tab" onclick="switchTab('absent')">Absent</button>
    </div>

    <div class="action-bar">
      <input type="text" id="searchInput" placeholder="Search name or ID..." oninput="renderTable()">
      <button class="btn btn-teal" onclick="openEnroll()">+ Add Student</button>
      <button class="btn btn-green" onclick="attendAll()">✓ Attend All</button>
      <button class="btn btn-red"   onclick="absentAll()">✗ Absent All</button>
      <button class="btn btn-gray"  onclick="exportCSV()">⬇ CSV</button>
    </div>
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
void loop() {
  handleButton();

  if (currentMode == MODE_SCAN_RESULT && millis() - lastScanTime > 4000) {
    currentMode = MODE_READY;
    showReady();
  }
  static unsigned long lastClockUpdate = 0;
  if (currentMode == MODE_READY && millis() - lastClockUpdate > 30000) {
    lastClockUpdate = millis();
    showReady();
  }
  static unsigned long lastEnrollPulse = 0;
  if (currentMode == MODE_ENROLL && millis() - lastEnrollPulse > 1000) {
    lastEnrollPulse = millis();
    showEnroll();
  }
  static unsigned long lastSettingsRefresh = 0;
  if (currentMode == MODE_SETTINGS && millis() - lastSettingsRefresh > 1000) {
    lastSettingsRefresh = millis();
    showSettings();
  }
  static unsigned long lastRFIDReinit = 0;
  if (millis() - lastRFIDReinit > 5000) {
    lastRFIDReinit = millis();
    rfid.PCD_Init();
  }

  if (currentMode != MODE_READY && currentMode != MODE_ENROLL &&
      currentMode != MODE_SETTINGS)
    return;

  if (!rfid.PICC_IsNewCardPresent()) { rfid.PCD_StopCrypto1(); return; }
  if (!rfid.PICC_ReadCardSerial())   { rfid.PICC_HaltA();      return; }

  str uid = uidToString(rfid.uid.uidByte, rfid.uid.size);
  

  display.clearDisplay();
  drawCenteredText(enrollPending ? "ENROLLING..." : "SCANNING...", 18);
  display.setTextSize(1);
  drawCenteredText(uid.c_str(), 36);
  display.display();

  str name, msg;
  bool ok = processRFID(uid, name, msg);

  if (ok) {
    soundSuccess();
    if (!enrollPending) totalScansToday++;
  } else if (msg == "Already checked in") {
    soundAlreadyScanned();
  } else {
    soundFail();
  }

  if (!enrollPending || !ok) {
    str sse = "{\"type\":\"scan\",\"ok\":" + str(ok ? "true" : "false") +
              ",\"name\":\"" + name + "\",\"message\":\"" + msg + "\"}";
    sseSource.send(sse.c_str(), NULL, millis());
  }

  lastScanTime = millis();
  if (currentMode != MODE_ENROLL) currentMode = MODE_SCAN_RESULT;
  showScanResult(ok, name, msg);

  rfid.PICC_HaltA();
  rfid.PCD_StopCrypto1();
}



void connectWiFi() {
  if (useSta && staSsid.length() > 0) {
    display.clearDisplay();
    drawCenteredText("Connecting WiFi", 3);
    String ssidShort = staSsid.length() > 14 ? staSsid.substring(0, 12) + ".." : staSsid;
    drawCenteredText(ssidShort.c_str(), 26);
    display.display();

    WiFi.mode(WIFI_AP_STA);
    WiFi.softAP(AP_SSID);          
    WiFi.begin(staSsid.c_str(), staPassword.c_str());
    staConnected = false;

    unsigned long t0 = millis();
    while (WiFi.status() != WL_CONNECTED && millis() - t0 < 8000) {
      delay(200);
    }
    staConnected = (WiFi.status() == WL_CONNECTED);

    str apIp  = WiFi.softAPIP().toString();
    str staIp = staConnected ? WiFi.localIP().toString() : "";
    
    if (staConnected) Serial.println("STA IP: " + staIp);
    else              Serial.println("STA connection failed");

    display.clearDisplay();
    drawCenteredText(staConnected ? "WiFi Connected!" : "WiFi Failed!", 4);
    display.setTextSize(1);
    display.setCursor(0, 18); display.print("AP:  "); display.println(apIp);
    if (staConnected) {
      display.setCursor(0, 30); display.print("STA: "); display.println(staIp);
    } else {
      display.setCursor(0, 30); display.print("SSID: "); display.println(ssidShort.c_str());
    }
    display.setCursor(0, 42); display.print("HotS: "); display.println(AP_SSID);
    display.display();
    delay(3500);
  } else {
    display.clearDisplay();
    drawCenteredText("Starting Hotspot", 3);
    drawCenteredText(AP_SSID, 26);
    display.display();

    WiFi.mode(WIFI_AP);
    WiFi.softAP(AP_SSID);          

    str ip = WiFi.softAPIP().toString();
    

    display.clearDisplay();
    drawCenteredText("Hotspot Ready!", 4);
    display.setTextSize(1);
    display.setCursor(0, 18); display.print("SSID: "); display.println(AP_SSID);
    display.setCursor(0, 30); display.print("Open Access");
    display.setCursor(0, 42); display.print("IP:   "); display.println(ip);
    display.display();
    delay(3500);
  }
}


void loadConfig() {
  if (!SPIFFS.exists("/config.json")) {
    useSta = false; staSsid = ""; staPassword = ""; return;
  }
  File f = SPIFFS.open("/config.json", "r");
  if (!f) return;
  DynamicJsonDocument doc(512);
  if (!deserializeJson(doc, f)) {
    useSta      = doc["useSta"] | false;
    staSsid     = doc["ssid"].as<String>();
    staPassword = doc["password"].as<String>();
  }
  f.close();
}
void saveConfig() {
  DynamicJsonDocument doc(512);
  doc["useSta"]   = useSta;
  doc["ssid"]     = staSsid;
  doc["password"] = staPassword;
  File f = SPIFFS.open("/config.json", "w");
  if (!f) return;
  serializeJson(doc, f);
  f.close();
}


str uidToString(byte *buf, byte len) {
  str s = "";
  for (byte i = 0; i < len; i++) {
    if (buf[i] < 0x10) s += "0";
    s += str(buf[i], HEX);
    if (i < len - 1) s += ":";
  }
  s.toUpperCase();
  return s;
}


void drawCenteredText(const char *text, int y, bool large) {
  display.setTextSize(large ? 2 : 1);
  int16_t x1, y1; uint16_t w, h;
  display.getTextBounds(text, 0, y, &x1, &y1, &w, &h);
  display.setCursor((SCREEN_WIDTH - w) / 2, y);
  display.print(text);
}


void showReady() {
  display.clearDisplay();
  display.fillRect(0, 0, 128, 14, SSD1306_WHITE);
  display.setTextColor(SSD1306_BLACK);
  display.setCursor(2, 3); display.setTextSize(1); display.print("AttendX");
  display.setTextColor(SSD1306_WHITE);
  drawCenteredText(getCurrentTimeDisplay().c_str(), 20, true);
  display.setTextSize(1);
  drawCenteredText(getCurrentDateDisplay().c_str(), 38);
  display.drawLine(0, 50, 128, 50, SSD1306_WHITE);
  drawCenteredText("Scan your card...", 55);
  display.display();
}
void showEnroll() {
  display.clearDisplay();
  display.fillRect(0, 0, 128, 14, SSD1306_WHITE);
  display.setTextColor(SSD1306_BLACK);
  display.setCursor(2, 3); display.setTextSize(1); display.print("ENROLL STUDENT");
  display.setTextColor(SSD1306_WHITE);
  display.setTextSize(2);
  drawCenteredText("SCAN", 18, true);
  display.setTextSize(1);
  drawCenteredText("CARD", 38);
  display.drawLine(0, 50, 128, 50, SSD1306_WHITE);
  str n = "For: " + enrollName;
  if (n.length() > 18) n = n.substring(0, 17) + "..";
  drawCenteredText(n.c_str(), 55);
  display.display();
}
void showScanResult(bool ok, str name, str msg) {
  display.clearDisplay();
  display.fillRect(0, 0, 128, 14, SSD1306_WHITE);
  display.setTextColor(SSD1306_BLACK);
  display.setCursor(2, 3); display.setTextSize(1);
  display.print(ok ? "ACCESS GRANTED" : (name.length() > 0 ? "ALREADY SCANNED" : "ACCESS DENIED"));
  display.setTextColor(SSD1306_WHITE);
  if (ok) {
    display.drawLine(10, 35, 16, 42, SSD1306_WHITE); display.drawLine(16, 42, 28, 28, SSD1306_WHITE);
    display.drawLine(11, 35, 17, 43, SSD1306_WHITE); display.drawLine(17, 43, 29, 28, SSD1306_WHITE);
  } else {
    display.drawLine(10, 28, 26, 44, SSD1306_WHITE); display.drawLine(26, 28, 10, 44, SSD1306_WHITE);
    display.drawLine(11, 28, 27, 44, SSD1306_WHITE); display.drawLine(27, 28, 11, 44, SSD1306_WHITE);
  }
  display.setTextSize(1);
  if (name.length() > 0) { display.setCursor(35, 26); display.print(name.substring(0, 14)); }
  display.setCursor(35, 38); display.print(msg.substring(0, 14));
  display.drawLine(0, 52, 128, 52, SSD1306_WHITE);
  drawCenteredText(getCurrentTimeDisplay().c_str(), 56);
  display.display();
}
void showAttended() {
  display.clearDisplay();
  display.fillRect(0, 0, 128, 14, SSD1306_WHITE);
  display.setTextColor(SSD1306_BLACK);
  display.setCursor(2, 3); display.setTextSize(1); display.print("ATTENDED TODAY");
  display.setTextColor(SSD1306_WHITE);
  DynamicJsonDocument studs = loadStudents();
  DynamicJsonDocument att   = loadAttendance();
  JsonArray sArr = studs.as<JsonArray>(), aArr = att.as<JsonArray>();
  str today = getCurrentDate(); int count = 0;
  for (JsonObject s : sArr) {
    str uid = s["uid"].as<str>();
    for (JsonObject r : aArr)
      if (r["uid"].as<str>() == uid && r["date"].as<str>() == today) { count++; break; }
  }
  display.drawLine(10,35,16,42,SSD1306_WHITE); display.drawLine(16,42,28,28,SSD1306_WHITE);
  display.drawLine(11,35,17,43,SSD1306_WHITE); display.drawLine(17,43,29,28,SSD1306_WHITE);
  display.setTextSize(3);
  str cs = str(count); int16_t x1,y1; uint16_t w,h;
  display.getTextBounds(cs.c_str(),0,0,&x1,&y1,&w,&h);
  display.setCursor(128-w-6,22); display.print(cs);
  display.setTextSize(1); display.drawLine(0,48,128,48,SSD1306_WHITE);
  drawCenteredText("[BTN] Next", 56); display.display();
}
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

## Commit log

2026-04-06 Initial Release
    [bottom.stl, project.stl]
2026-04-06 Added top.stl
    [top.stl]
